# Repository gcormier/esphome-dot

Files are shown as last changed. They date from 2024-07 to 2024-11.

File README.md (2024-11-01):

# esphome-dot

Beginnings of a replacement PCB for Amazon Echo Dot v5.

# todo
- [x] Physical board dimensions
- [ ] Figure out pinout of ribbon cable
- [ ] figure out PDN mystery. it needs to be controlled to use register 0x00 for pullup settings
- [ ] Determine if ESP32 module can be used or needs custom design for RF purposes
- [ ] Schematic
- [ ] PCB design and layout
- [ ] BOM
- [ ] Firmware
- [ ] Manufacture

## dfm
- [ ] Holes around spring fingers for protective cap (1.6mm hole, 1.5mm plastic pin)

## Notice
Amazon Echo Dot is a trademark of Amazon.com, Inc. This project is not affiliated with Amazon.com, Inc. in any way.

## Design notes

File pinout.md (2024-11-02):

# Pinout

| Pin | Value | Connected | Pin | Value | Connected |
| --- | ----- | --- | --- | ----- | --- |
| 1 | GND | - | 2 | AVDD  | 3.3V AK PIN18 |
| 3 | BTN | Alexa, pulled up| 4 | BTNINT| Pulled low when volume button pushed |
| 5 | | - | 6 | SDA | AK PIN6 |
| 7 | | - | 8 | LRCK  | AK PIN7 |
| 9 | | - | 10  | GND | - |
| 11  | MCKI  | AK PIN10 | 12  | GND | - |
| 13  | BCLK  | AK PIN11 | 14  | GND | - |
| 15  | GND | - | 16  | GND | - |
| 17  | SDTO1 | via buffer | 18  | | - |
| 19  | | - | 20  | | - |
| 21  | SCL | AK PIN2 | 22  | | - |
| 23  | TVDD  | 1.8V AK PIN23 | 24  | | - |
| 25  | | - | 26  | | - |
| 27  | | - | 28  | | - |

## Test Points
TM24 - Mute button  
tm17 button
tm18 - button near ribbon

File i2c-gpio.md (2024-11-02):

# i2c gpio
i2c device is 0x08

cmos buffer gate is bottom left bin for OE

Device at 0x08
    - Registers written to: 0xF4, 0xF5, 0xF1, 0xF0
    - Registers read from: 0xF4, 0xF5, 0xF1, 0xF0

# Register 0xF1
Something to do with mute LED
0x62 when light off
0x40 when light on
bits 7 and 2 flip
One probably drives LED's, the other probably drives the output enable pin on the cmos buffer

# Register 0xF4
BITS
MSB 12345678 LSB

Bit 7 is the MUTE LED
Bit 5 is the PDN pin
W,F4,00 - this seems to bring ADC online!
W,0xf4, 04 - turns it off

# Register 0xF5
R,0xF5,1
bit 1 and 2 are related to mute
one probably controls the LED's
bit 3, far button
bit 4, is FPC button
bit 7, something has changed

RESET INPUT REGISTERS - 
Write 0D to F4, then 0C to F4
toggles LSB once which resets the registers
w,0xf4,0d
w,0xf4,0c

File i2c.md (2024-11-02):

esptool.py --chip esp32s3 --port /dev/ttyACM0 erase_flash
# i2c

# Devices
## 0x39 (57 decimal)
This is TSL25403 light sensor, https://www.mouser.ca/datasheet/2/588/asset_pdf_25493362-3432743.pdf

## What we want
1. Set DMIC1 DMIC2 to 1
1. Set MONON to 1 and PMDM1B to 1, PMDM1A to 0
2. 0x0e - Set audio format to is2, mono, 16-bit

## Our Sequence
1. Set 0x00 to 00100000 (Set MSN to 1)
1. Set 0x01 to 0x80 (VCOM powerup via PMVCM)

1. Set 0x04 to 0xF4 (MONON set, rest stock)
1. Set 0x05 to 0x11 (MIC gain, stock)
1. Don't touch 0x07 based on stock
1. Set 0x08 to 00 00 1010
1. Do something with PLL's on 0x0A B C D!
1. Set 0x0E to 0x10 (i2s, 16-bit, stereo)
1. Set 0x00 to 0x27
1. Set 0x13 to 0x70 (highpass filter, stock)
1. Set 0x26 to 0x00 (ALC1, stock)
1. Set 0x2B to 0x96 (volume, stock)
1. Set 0x41 to 0xDF (stock)
1. Set 0x42 to 0x8E (stock)

1. Set 0x01 to 0x8F (Bring up all MIC POWER)
1. Set 0x02 to 0x02 (Power only 1B analog mic)
1. Set 0x03 to 0x0F (Match stock init, filters on)
1. Set 0x01 to 0xCF (Bring up PLL)

## Power-on sequence
Here's what happens when the power is turned on for the AK5407
```
(register) (data)
0x26 0x00 # ALC1 
0x13 0x70 # ADC high pass
0x41 0xDF 
0x42 0x8E 
0x01 0x80 #power management
0x04 0xF0 #mic input

0x00 0x20 # flow control (MSN = 1)
0x0E 0x45 # AUDIO FORMAT pg85 = 0100 0101
            = 24-bit data length
            = page 38, Mode 13
            = MSB justified :()

0x00 0x21 # flow control
0x00 0x23 # flow control
 # flow control
0x0E 0x65 # AUDIO FORMAT AGAIN
            Changing data length to be 32-bit length
0x05 0x61 # mic1 amp gain
0x05 0x11 # more amp gain
0x06 0x61 # more amp gain
0x06 0x11 # mic2 amp gain
0x27 0x96 #volume
0x28 0x96 #volume 
0x2B 0x96 #vol
0x2C 0x96 #vol

0x08 0x0D # CLOCK MODE 
            = 25fs
            = 96kHz
0x0B 0x27 # pll
           
0x0D 0x63 # pll
0x01 0x8F # power mgmt
0x02 0x0F # power mgmt 2
0x03 0x0F # power mgmt 3
0x01 0xCF # power mgmt
```

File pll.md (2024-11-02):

## PLL Notes
8.8 pg 18
fMCK = 12Mhz

LRCK = 48Khz
BCLK = 32*fs = 1.536Mhz

MCKI frequency
will be 128fs, 256fs, 512fs or 1024fs from 9.3

Master clock CM bits
sample freq FS bits

Register 0x08 stock is 0x0D which is

CM = 00 = 256fs
FS = 1101 = 97kHz

try
MCKI = 9.6Mhz
fs = 48khz
PLD 000EH
PLM 005FH
FS 1010
CM 00

MCKI = 16MHz
fs = 48khz
PLD = 0018h
PLM = 005Fh
FS 1010b
CM 00b

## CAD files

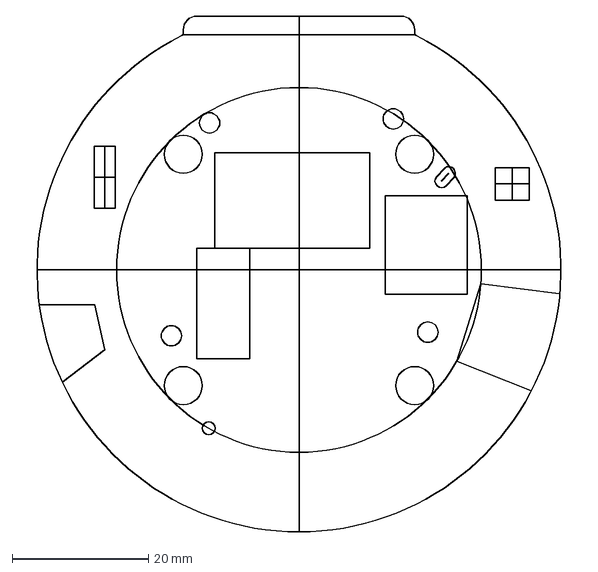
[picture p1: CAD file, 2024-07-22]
pcb/pcb2.dxf
83.2 x 75.8 mm

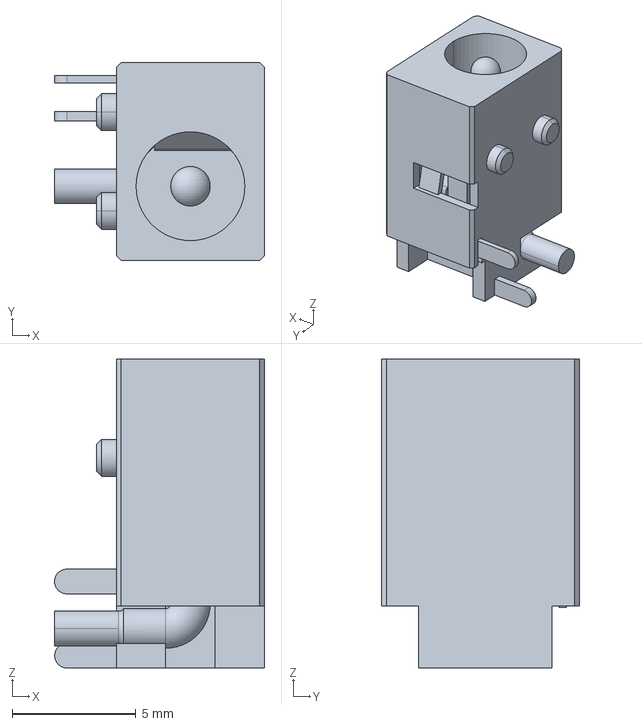
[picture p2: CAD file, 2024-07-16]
pcb/ADC-055B-9.stp
8.51 x 8.00 x 12.5 mm

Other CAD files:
pcb/ADC-055B-9.dxf

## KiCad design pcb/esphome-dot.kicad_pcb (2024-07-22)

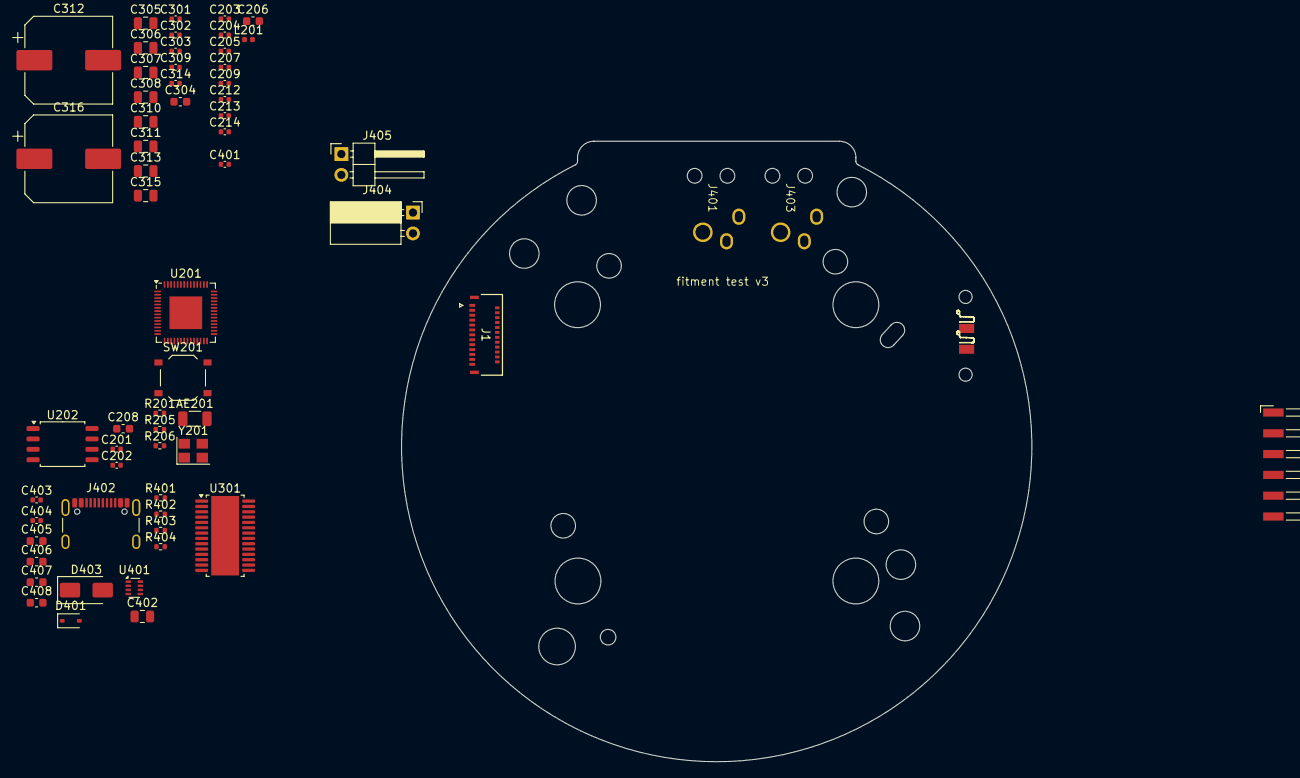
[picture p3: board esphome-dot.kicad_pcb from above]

Board: 4 copper layers, 77.0 x 75.8 mm, 62 parts (0 on the bottom side), 44 nets, no tracks yet.

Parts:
AE201: ANT3216LL00R2400A; C_1206_3216Metric
C201, C202: 20pF; C_0402_1005Metric
C203, C205, C207, C209, C212, C213, C214, C303, C309, C314, C401, C403, C404: 100n; C_0402_1005Metric
C204, C301, C302: 1u; C_0402_1005Metric
C206, C208, C304, C405, C407, C408: 10u; C_0603_1608Metric
C305, C306, C307, C308: 220n; C_0805_2012Metric
C310, C315: 22u; C_0805_2012Metric
C311, C313: 680n; C_0805_2012Metric
C312, C316: 330u; CP_Elec_10x10.5
C402: 10u; C_0805_2012Metric
C406: 27p; C_0603_1608Metric
D401: CUS05S40.H3F; D_SOD-323
D403: SMAJ22A; D_SMA
J1: Input; CONN_502598-2593_MOLEX
J5: SPK1; SF2212
J6: SPK2; SF2212
J201: eflashy32; Harwin_M20-89006xx_1x06_P2.54mm_Horizontal
J401, J403: ADC-055B-9; BarrelJack_AdamTech_ADC-055B-9
J402: USBC; USB_C_Receptacle_GCT_USB4105-xx-A_16P_TopMnt_Horizontal
J404: 20V; PinSocket_1x02_P2.54mm_Horizontal
J405: 20v; PinHeader_1x02_P2.54mm_Horizontal
L201: 2nH; L_0402_1005Metric
R201: 22; R_0402_1005Metric
R205, R206: 10k; R_0402_1005Metric
R401, R402: 5k1; R_0402_1005Metric
R403: 68k; R_0402_1005Metric
R404: 22k; R_0402_1005Metric
SW201: RESET; SW_Push_1P1T_XKB_TS-1187A
U201: ESP32-S3R8; QFN-56-1EP_7x7mm_P0.4mm_EP4x4mm
U202: W25Q128JVSIQ; SOIC-8_5.23x5.23mm_P1.27mm
U301: TAS5805M; TSSOP-28-1EP_4.4x9.7mm_P0.65mm_EP3.4x9.7mm_Mask3.1x4.05mm
U401: TPS62932; SOT-583-8
Y201: 40MHz; Crystal_SMD_3225-4Pin_3.2x2.5mm

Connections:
3V3: C203.2, C204.2, C205.2, C206.2, C212.2, C213.2, C214.2, L201.1, U201.20 (VDD3P3_RTC), U201.46 (VDD3P3_CPU), U201.55 (VDDA), U201.56 (VDDA)
3V3_RF: C209.2, L201.2, U201.2 (VDD3P3), U201.3 (VDD3P3)
+3V3: C303.1, C304.1, C405.1, C406.1, C407.1, C408.1, J201.4, R205.1, R206.1, R403.2, U301.2 (DVDD)
+20V: C309.2, C310.2, C312.2, C314.2, C315.2, C316.2, C402.1, C403.2, D401.1 (K), D403.1 (K), J403.1, J405.1, U301.15 (PVDD), U301.16 (PVDD), U301.27 (PVDD), U301.28 (PVDD), U401.3 (VIN)
/MCU/EN: C208.2, J201.5, R205.2, U201.4 (CHIP_PU)
/MCU/GPIO0: J201.6, R206.2, SW201.1 (A), U201.5 (GPIO0)
/MCU/PROGRXD: J201.3, U201.50 (U0RXD)
/MCU/PROGTXD: J201.2, U201.49 (U0TXD)
/MCU/XTAL_N: C202.2, U201.53 (XTAL_N), Y201.3
/MCU/XTAL_P: R201.1, U201.54 (XTAL_P)
/Power/BST: C404.2, U401.6 (BST)
/Power/FB: C406.2, R403.1, R404.1, U401.8 (FB)
/Power/SW: C404.1, U401.5 (SW)
ADR: U201.41 (GPIO36), U301.3 (ADR)
GND: C201.1, C202.1, C203.1, C204.1, C205.1, C206.1, C207.2, C208.1, C209.1, C212.1, C213.1, C214.1, C301.1, C302.1, C303.2, C304.2, C309.1, C310.1, C311.1, C312.1, C313.1, C314.1, C315.1, C316.1, C401.1, C402.2, C403.1, C405.2, C407.2, C408.2, D403.2 (A), J201.1, J401.2, J402.A1 (GND), J402.A12 (GND), J402.B1 (GND), J402.B12 (GND), J403.2, J404.2, J405.2, R401.2, R402.2, R404.2, SW201.2 (B), U201.57 (GND), U202.4 (GND), U301.1 (DGND), U301.5 (DGND), U301.14 (AGND), U301.19 (PGND), U301.24 (PGND), U301.29 (EP), U401.1 (RT), U401.4 (GND), Y201.2, Y201.4
I2C_SDA: U201.18 (GPIO13), U301.10 (SDA)
I2C_SDL: U201.17 (GPIO12), U301.11 (SCL)
I2S1_CLK: U201.10 (GPIO5), U301.7 (SCLK)
I2S1_FSYNC: U201.9 (GPIO4), U301.6 (LRCLK)
I2S1_SD: U201.11 (GPIO6), U301.8 (SDIN)
unnamed: C201.2, R201.2, Y201.1
unnamed: D401.2 (A), J402.A4 (VBUS), J402.A9 (VBUS), J402.B4 (VBUS), J402.B9 (VBUS)
unnamed: J402.A5 (CC1), R402.1
unnamed: J402.B5 (CC2), R401.1
unnamed: J401.1, J404.1
unnamed: C302.2, U301.13 (AVDD)
unnamed: C305.1, U301.25 (BST_A+)
unnamed: C308.1, U301.22 (BST_A-)
unnamed: C306.1, U301.18 (BST_B+)
unnamed: C307.1, U301.21 (BST_B-)
unnamed: C305.2, C308.2, U301.23 (OUT_A-), U301.26 (OUT_A+)
unnamed: C306.2, C307.2, U301.17 (OUT_B+), U301.20 (OUT_B-)
unnamed: C301.2, U301.4 (VR_DIG)
unnamed: C401.2, U401.7 (SS)
PDN: U201.40 (GPIO35), U301.12 (~PDN)
SPI_CLK: U201.33 (SPICLK), U202.6 (CLK)
SPI_CS0: U201.32 (SPICS0), U202.1 (~CS)
SPI_DI: U201.35 (SPID), U202.5 (DI(IO0))
SPI_DO: U201.34 (SPIQ), U202.2 (DO(IO1))
SPI_HD: U201.30 (SPIHD), U202.7 (IO3)
SPI_WP: U201.31 (SPIWP), U202.3 (IO2)
USB+: J402.A6 (D+), J402.B6 (D+), U201.26 (GPIO20/USB_D+)
USB-: J402.A7 (D-), J402.B7 (D-), U201.25 (GPIO19/USB_D-)
VDD_SPI: C207.1, U201.29 (VDD_SPI), U202.8 (VCC)

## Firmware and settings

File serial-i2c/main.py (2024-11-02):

from machine import Pin, UART, I2C
import binascii

led = Pin(7, Pin.OUT)
alert = Pin(6, Pin.IN, Pin.PULL_UP)

i2c = I2C(0, scl = Pin(13), sda = Pin(14), freq = 200000)

commands = {
    "S": lambda: ",".join(str(addr) for addr in i2c.scan()),
    "R": lambda reg, len: binascii.hexlify(i2c.readfrom_mem(8, int(reg), int(len))).decode("ascii"),
    "W": lambda reg, data: i2c.writeto_mem(8, int(reg),binascii.unhexlify(data)),
    "A": lambda: str("F" if alert.value() == 1 else "T")
}

def do(cmd):
    led.value(1)
    try:
        cmd = cmd.upper()
        cmd = cmd.split(",")
        cmd = [x.strip() for x in cmd]

        if cmd[0] in commands:
            result = commands[cmd[0]](*cmd[1:])
            return str(result)
        else:
            raise Exception("Unknown command. Try S, R, W, A.")

    finally:
        led.value(0)

# print(do("S"))
# print(do(" R , 79 , 2 "))
# print(do(" W , 79, 0000 "))
# print(do(" A "))
# print(do(" W , 10, 0000 "))

while True:
    try:
        print(do(input()))
    except Exception as e:
        print("!" + str(e))

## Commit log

2024-06-08 test pcb
    [esphome-dot.kicad_pcb, esphome-dot.kicad_sch]
2024-07-16 3d model
    [ADC-055B-9.stp]
2024-07-22 fix footprint
2024-07-22 schematic and tweaks
    [audio.kicad_sch, esphome-dot.kicad_pcb, mcu.kicad_sch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]
2024-11-02 i2c works
